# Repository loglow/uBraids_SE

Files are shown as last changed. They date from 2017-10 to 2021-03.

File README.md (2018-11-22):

# µBraids SE (uBraids, microBraids) Eurorack [Rev E]

## 8HP Eurorack module | Voltage-controlled digital oscillator

[µBraids SE](http://ubraids-se.com) is a voltage-controlled digital oscillator/sound source in 8HP with a wide range of creative and useful sound generation algorithms (aka models).

This re-engineered Eurorack module updates and simplifies the classic [Mutable Instruments Braids](https://mutable-instruments.net/modules/braids/) design with a custom brilliant orange LED display module protected by a clear acrylic lens, a low-profile rotary encoder, and an added attenuverter.

Fully compatible with upstream Braids firmware. Includes power cable, mounting hardware, and a one-year warranty. Designed and built with care by [Tall Dog Electronics](http://tall-dog.com) in Western Massachusetts. Licensed [CC BY-SA 4.0](https://creativecommons.org/licenses/by-sa/4.0/) open source hardware.

- **Height:** 3U (128.5 mm)
- **Width:** 8HP (40.3 mm)
- **Depth:** 31 mm (with power)
- **+12V:** 100 mA (average)
- **-12V:** 15 mA (average)

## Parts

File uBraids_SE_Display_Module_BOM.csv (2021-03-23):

Reference | Quantity | Description | Manufacturer | Part Number | Digi-Key P/N
A1 A2 A3 A4 | 4 | DISPLAY 610NM ORN 1DIG 0.4" SMD | Kingbright | ACPSC04-41SEKWA | ACPSC04-41SEKWA-ND
C1 C2 | 2 | CAP CER 0.1UF 50V X7R 0603 | Samsung | CL10B104JB8NNNC | 1276-1033-1-ND
H1 | 1 | CONN HDR 5POS 0.1 STACK T/H GOLD | Samtec | DW-05-15-F-S-200 | DW-05-15-F-S-200-ND
H2 | 1 | CONN HDR 9POS 0.1 STACK T/H GOLD | Samtec | DW-09-15-F-S-200 | N/A
Q1 Q2 Q3 Q4 | 4 | TRANS NPN 40V 0.2A SMD SOT23-3 | Diodes Incorporated | MMBT3904-7-F | MMBT3904-FDICT-ND
R1 R2 R3 R4 | 4 | RES SMD 1K OHM 1% 1/10W 0603 | Panasonic | ERJ-3EKF1001V | P1.00KHCT-ND
R5 R6 R7 R8 R9 R10 R11 R12 R13 R14 R15 R16 R17 R18 | 14 | RES SMD 100 OHM 1% 1/10W 0603 | Panasonic | ERJ-3EKF1000V | P100HCT-ND
U1 U2 | 2 | IC 8BIT SHIFT REGISTER 16-TSSOP | Texas Instruments | SN74HC595PWR | 296-23258-1-ND

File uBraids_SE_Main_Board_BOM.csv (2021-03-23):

Reference | Quantity | Description | Manufacturer | Part Number | Digi-Key P/N
C1 C7 | 2 | CAP CER 18PF 50V NP0 0603 | Samsung | CL10C180FB8NNNC | 1276-2206-1-ND
C2 C3 C4 C5 C6 C10 C11 C15 C17 C18 C21 C23 C26 C28 C29 | 15 | CAP CER 0.1UF 50V X7R 0603 | Samsung | CL10B104JB8NNNC | 1276-1033-1-ND
C8 C9 | 2 | CAP CER 1UF 25V X7R 0603 | Samsung | CL10B105KA8NNNC | 1276-1184-1-ND
C12 C14 | 2 | CAP 22 UF 20% 25 V | Wurth | 865230443003 | 732-8260-1-ND
C13 | 1 | CAP CER 0.47UF 25V X7R 0603 | Samsung | CL10B474KA8NFNC | 1276-2082-1-ND
C16 C19 | 2 | CAP 47 UF 20% 25 V | Wurth | 865230445005 | 732-8262-1-ND
C20 C22 C24 C30 | 4 | CAP CER 1000PF 50V X7R 0603 | Samsung | CL10B102JB8NNNC | 1276-1194-1-ND
C25 C27 | 2 | CAP CER 100PF 50V C0G/NP0 0603 | Samsung | CL10C101FB8NNNC | 1276-2159-1-ND
C31 | 1 | CAP CER 47PF 50V NP0 0603 | Samsung | CL10C470FB8NNNC | 1276-2293-1-ND
C32 | 1 | CAP 10 UF 20% 25 V | Wurth | 865230440002 | 732-8259-1-ND
D1 D2 | 2 | DIODE SCHOTTKY 40V 1A SOD123 | Diodes Incorporated | 1N5819HW-7-F | 1N5819HW-FDICT-ND
H1 | 1 | CONN RCPT 9POS 0.1 GOLD SMD | Samtec | SSM-109-S-SV-BE | SSM-109-S-SV-BE-ND
H2 | 1 | IDC BOX HEADER 0.050 10 POS | CNC Tech | 3220-10-0300-00 | 1175-1629-ND
H4 | 1 | CONN RCPT 5POS 0.1 GOLD SMD | Samtec | SSM-105-S-SV-BE | SSM-105-S-SV-BE-ND
H5 | 1 | CONN HEADER VERT 10POS GOLD | On Shore Technology | 302-S101 | ED1543-ND
J1 J2 J3 J4 J5 J6 | 6 | 3.5MM JACK VERTICAL PCB MOUNT | Wenzhou QingPu | WQP-PJ398SM | N/A
P1 P2 P5 P7 | 4 | POT 9MM LINEAR B10K | Song Huei | R0904N-B10K,L-25KQ/LWS | N/A
P3 P4 P6 | 3 | POT 9MM LINEAR B10K CENTER | Song Huei | R0904N-B10K,L-25KQ/LWS/CC | N/A
Q1 | 1 | TRANS NPN 40V 0.2A SOT23 | ON Semiconductor | MMBT3904LT1G | MMBT3904LT1GOSCT-ND
R1 R5 | 2 | RES SMD 10K OHM 0.1% 1/10W 0603 | Susumu | RG1608P-103-B-T5 | RG16P10.0KBCT-ND
R2 R3 | 2 | RES SMD 100 OHM 1% 1/10W 0603 | Panasonic | ERJ-3EKF1000V | P100HCT-ND
R4 R31 | 2 | RES SMD 1K OHM 0.1% 1/10W 0603 | Susumu | RG1608P-102-B-T5 | RG16P1.0KBCT-ND
R6 R10 R18 R26 R27 R32 | 6 | RES SMD 100K OHM 0.1% 1/10W 0603 | Susumu | RG1608P-104-B-T5 | RG16P100KBCT-ND
R7 | 1 | RES SMD 4.7 OHM 1% 1/2W 0805 | Panasonic | ERJ-6DQF4R7V | P19284CT-ND
R8 | 1 | RES SMD 330 OHM 1% 1/2W 0805 | Panasonic | ERJ-P6WF3300V | P16879CT-ND
R9 | 1 | RES SMD 120K OHM 0.1% 1/10W 0603 | Susumu | RG1608P-124-B-T5 | RG16P120KBCT-ND
R11 R22 R30 | 3 | RES SMD 200K OHM 0.1% 1/10W 0603 | Susumu | RG1608P-204-B-T5 | RG16P200KBCT-ND
R12 R13 R14 R15 R16 R17 R19 R23 R25 R29 R33 | 11 | RES SMD 24.9KOHM 0.1% 1/10W 0603 | Susumu | RG1608P-2492-B-T5 | RG16P24.9KBCT-ND
R20 R28 | 2 | RES SMD 49.9KOHM 0.1% 1/10W 0603 | Susumu | RG1608P-4992-B-T5 | RG16P49.9KBCT-ND
R21 R24 | 2 | RES SMD 39K OHM 0.1% 1/10W 0603 | Susumu | RG1608P-393-B-T5 | RG16P39.0KBCT-ND
S1 | 1 | ENCODER ROTARY | Song Huei | ED1212S-24P-24C-25KC | N/A
U1 | 1 | IC MCU 32BIT 128KB FLASH 48LQFP | STMicroelectronics | STM32F103CBT6 | 497-6288-ND
U2 | 1 | IC DAC 16BIT SNGL W/SPI 8VSSOP | Texas Instruments | DAC8551IADGKT | 296-21222-1-ND
U3 | 1 | IC VREF SHUNT 2.5V SOT23-3 | Texas Instruments | LM4040B25IDBZR | 296-20872-1-ND
U4 | 1 | IC ADC 12BIT 2.7V 4CH SPI14TSSOP | Microchip Technology | MCP3204-CI/ST | MCP3204-CI/ST-ND
U5 | 1 | IC REG LINEAR 3.3V 800MA SOT223 | Texas Instruments | LM1117IMP-3.3/NOPB | LM1117IMP-3.3/NOPBCT-ND
U6 | 1 | IC VREF SHUNT 10V SOT23-3 | Texas Instruments | LM4040B10IDBZR | 296-20869-1-ND
U7 | 1 | IC OPAMP GP 1MHZ RRO 14TSSOP | Microchip Technology | MCP6004T-I/ST | MCP6004T-I/STCT-ND
U8 | 1 | IC OPAMP JFET 3MHZ 14TSSOP | Texas Instruments | TL074CPWR | 296-7198-1-ND
U9 | 1 | IC OPAMP JFET 3MHZ 8TSSOP | Texas Instruments | TL072CPWR | 296-7193-1-ND
X1 | 1 | CRYSTAL 8.0000MHZ 18PF SMD | Abracon | ABM2-8.000MHZ-D4Y-T | 535-10870-1-ND

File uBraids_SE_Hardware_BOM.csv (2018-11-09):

Description | Quantity
Window Lens Insert, Acrylic, 2 mm | 1
Thonkiconn Knurled Nut, Steel, M6 | 6
Threaded Hex Standoff, Brass, M2.5 x 10 mm | 2
Standoff Screw, Button Head, Hex Socket, M2.5 x 6 mm | 2
Standoff Screw, Flat Head, Hex Socket, M2.5 x 6 mm | 2

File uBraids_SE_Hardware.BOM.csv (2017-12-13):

Line | Description | Quantity | Notes
1 | Encoder Spacer, Black PLA, M7 x 2 mm | 1 | 3D printed part
2 | Encoder Shim, Black PLA, 1.2 mm | 1 | 3D printed part
3 | Encoder Washer, Steel, M7 x 0.5 mm | 1 | Included with part S3
4 | Encoder Hex Nut, Steel, M7 | 1 | Included with part S3
5 | Encoder Knob, D-Shaft, Sifam Soft Touch, Black, 10 mm | 1 | https://www.thonk.co.uk/shop/sifam-soft-touch-encoder-knobs/
6 | Thonkiconn Knurled Nut, Steel, M6 | 6 | https://www.thonk.co.uk/shop/3-5mm-jacks/
7 | Threaded Hex Standoff, Brass, M2.5 x 10 mm | 2 | https://www.ebay.com/itm/141137666898
8 | Standoff Screw, Button Head, Hex Socket, Black, M2.5 x 6 mm | 4 | https://www.ebay.com/itm/162503642542

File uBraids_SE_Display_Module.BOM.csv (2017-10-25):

Line | Reference | Quantity | Description | Package | Manufacturer | Part Number | Digi-Key P/N
1 | A1,A2,A3,A4 | 4 | DISPLAY 610NM ORN 1DIG 0.4" SMD | N/A | Kingbright | ACPSC04-41SEKWA | ACPSC04-41SEKWA-ND
2 | C1,C2 | 2 | CAP CER 0.1UF 50V X7R 0603 | 0603 | Samsung | CL10B104JB8NNNC | 1276-1033-1-ND
3 | H1 | 1 | .025" BOARD SPACERS | N/A | Samtec | DW-05-07-T-S-200 | DW-05-07-T-S-200-ND
4 | H2 | 1 | .025" BOARD SPACERS | N/A | Samtec | DW-09-07-T-S-200 | DW-09-07-T-S-200-ND
5 | Q1,Q2,Q3,Q4 | 4 | TRANS NPN 40V 0.2A SC70-3 | SOT-323 | Diodes Incorporated | MMST3904-7-F | MMST3904-FDICT-ND
6 | R1,R2,R3,R4 | 4 | RES SMD 1K OHM 1% 1/10W 0603 | 0603 | Panasonic | ERJ-3EKF1001V | P1.00KHCT-ND
7 | R5,R6,R7,R8,R9,R10,R11,R12,R13,R14,R15,R16,R17,R18 | 14 | RES SMD 100 OHM 1% 1/10W 0603 | 0603 | Panasonic | ERJ-3EKF1000V | P100HCT-ND
8 | U1,U2 | 2 | IC 8BIT SHIFT REGISTER 16-TSSOP | TSSOP-16 | Texas Instruments | SN74HC595PWR | 296-23258-1-ND

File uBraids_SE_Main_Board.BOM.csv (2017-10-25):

Line | Reference | Quantity | Description | Package | Manufacturer | Part Number | Digi-Key P/N
1 | A1 | 1 | 4X14-SEGMENT 10MM DISPLAY | N/A | N/A | N/A | N/A
2 | C1,C6 | 2 | CAP CER 18PF 50V NP0 0603 | 0603 | Samsung | CL10C180FB8NNNC | 1276-2206-1-ND
3 | C2,C3,C4,C5,C8,C10,C14,C16,C17,C20,C22,C25,C26,C28 | 14 | CAP CER 0.1UF 50V X7R 0603 | 0603 | Samsung | CL10B104JB8NNNC | 1276-1033-1-ND
4 | C7,C9 | 2 | CAP CER 1UF 25V X7R 0603 | 0603 | Samsung | CL10B105KA8NNNC | 1276-1184-1-ND
5 | C11 | 1 | CAP CER 0.47UF 25V X7R 0603 | 0603 | Samsung | CL10B474KA8NFNC | 1276-2082-1-ND
6 | C12,C13 | 2 | CAP 22 UF 20% 25 V | N/A | Wurth Electronics | 865230443003 | 732-8260-1-ND
7 | C15,C18 | 2 | CAP 47 UF 20% 25 V | N/A | Wurth Electronics | 865230445005 | 732-8262-1-ND
8 | C19,C21,C23,C29 | 4 | CAP CER 1000PF 50V X7R 0603 | 0603 | Samsung | CL10B102JB8NNNC | 1276-1194-1-ND
9 | C24,C27 | 2 | CAP CER 100PF 50V C0G/NP0 0603 | 0603 | Samsung | CL10C101FB8NNNC | 1276-2159-1-ND
10 | C30 | 1 | CAP CER 47PF 50V NP0 0603 | 0603 | Samsung | CL10C470FB8NNNC | 1276-2293-1-ND
11 | C31 | 1 | CAP 10 UF 20% 25 V | N/A | Wurth Electronics | 865230440002 | 732-8259-1-ND
12 | D1,D2 | 2 | DIODE SCHOTTKY 40V 1A SOD123 | SOD-123 | Diodes Incorporated | 1N5819HW-7-F | 1N5819HW-FDICT-ND
13 | H1 | 1 | IDC BOX HEADER 0.050 10 POS | N/A | CNC Tech | 3220-10-0300-00 | 1175-1629-ND
14 | H2 | 1 | CONN HEADER XH TOP 6POS 2.5MM | N/A | JST | B6B-XH-A(LF)(SN) | 455-2271-ND
15 | H3 | 1 | CONN HEADER VERT 10POS GOLD | N/A | On Shore Technology | 302-S101 | ED1543-ND
16 | J1,J2,J3,J4,J5,J6 | 6 | THONKICONN 3.5MM JACK | N/A | Thonk | PJ301M-12 | N/A
17 | P1,P2,P3,P4,P5,P6 | 6 | B10K LINEAR 9MM POT | N/A | Thonk | R0904N-B10K,L-25KQ | N/A
18 | Q1 | 1 | TRANS NPN 40V 0.2A SOT23 | SOT-23 | ON Semiconductor | MMBT3904LT1G | MMBT3904LT1GOSCT-ND
19 | R1,R2,R5 | 3 | RES SMD 10K OHM 1% 1/10W 0603 | 0603 | Panasonic | ERJ-3EKF1002V | P10.0KHCT-ND
20 | R3,R30 | 2 | RES SMD 1K OHM 1% 1/10W 0603 | 0603 | Panasonic | ERJ-3EKF1001V | P1.00KHCT-ND
21 | R4 | 1 | RES SMD 4.7 OHM 1% 1/2W 0805 | 0805 | Panasonic | ERJ-6DQF4R7V | P19284CT-ND
22 | R6,R8,R17,R25,R26,R31 | 6 | RES SMD 100K OHM 1% 1/10W 0603 | 0603 | Panasonic | ERJ-3EKF1003V | P100KHCT-ND
23 | R7 | 1 | RES SMD 330 OHM 1% 1/2W 0805 | 0805 | Panasonic | ERJ-P6WF3300V | P16879CT-ND
24 | R9,R22,R29 | 3 | RES SMD 200K OHM 1% 1/10W 0603 | 0603 | Panasonic | ERJ-3EKF2003V | P200KHCT-ND
25 | R10,R12,R13,R14,R15,R16,R18,R21,R23,R28,R32 | 11 | RES SMD 24.9K OHM 1% 1/10W 0603 | 0603 | Panasonic | ERJ-3EKF2492V | P24.9KHCT-ND
26 | R11 | 1 | RES SMD 120K OHM 1% 1/10W 0603 | 0603 | Panasonic | ERJ-3EKF1203V | P120KHCT-ND
27 | R19,R27 | 2 | RES SMD 49.9K OHM 1% 1/10W 0603 | 0603 | Panasonic | ERJ-3EKF4992V | P49.9KHCT-ND
28 | R20,R24 | 2 | RES SMD 39K OHM 1% 1/10W 0603 | 0603 | Panasonic | ERJ-3EKF3902V | P39.0KHCT-ND
29 | S1,S2 | 2 | SWITCH TACTILE SPST-NO 0.02A 15V | N/A | Panasonic | EVQ-Q2K01W | P12941SCT-ND
30 | S3 | 1 | ENCODER ROTARY | N/A | Bourns | PEC11R-4220F-S0024 | PEC11R-4220F-S0024-ND
31 | U1 | 1 | IC MCU 32BIT 128KB FLASH 48LQFP | LQFP-48 | STMicroelectronics | STM32F103CBT6 | 497-6288-ND
32 | U2 | 1 | IC DAC 16BIT SNGL W/SPI 8VSSOP | VSSOP-8 | Texas Instruments | DAC8551IADGKT | 296-21222-1-ND
33 | U3 | 1 | IC VREF SHUNT 2.5V SOT23-3 | SOT-23 | Texas Instruments | LM4040B25IDBZR | 296-20872-1-ND
34 | U4 | 1 | IC ADC 12BIT 2.7V 4CH SPI14TSSOP | TSSOP-14 | Microchip Technology | MCP3204-CI/ST | MCP3204-CI/ST-ND
35 | U5 | 1 | IC REG LDO 3.3V 0.8A 8WSON | WSON-8 | Texas Instruments | LM1117LD-3.3/NOPB | LM1117LD-3.3/NOPBCT-ND
36 | U6 | 1 | IC VREF SHUNT 10V SOT23-3 | SOT-23 | Texas Instruments | LM4040B10IDBZR | 296-20869-1-ND
37 | U7 | 1 | IC OPAMP GP 1MHZ RRO 14TSSOP | TSSOP-14 | Microchip Technology | MCP6004T-I/ST | MCP6004T-I/STCT-ND
38 | U8 | 1 | IC OPAMP JFET 3MHZ 14TSSOP | TSSOP-14 | Texas Instruments | TL074CPWR | 296-7198-1-ND
39 | U9 | 1 | IC OPAMP JFET 3MHZ 8TSSOP | TSSOP-8 | Texas Instruments | TL072CPWR | 296-7193-1-ND
40 | X1 | 1 | CRYSTAL 8.0000MHZ 18PF SMD | N/A | Abracon | ABM2-8.000MHZ-D4Y-T | 535-10870-1-ND

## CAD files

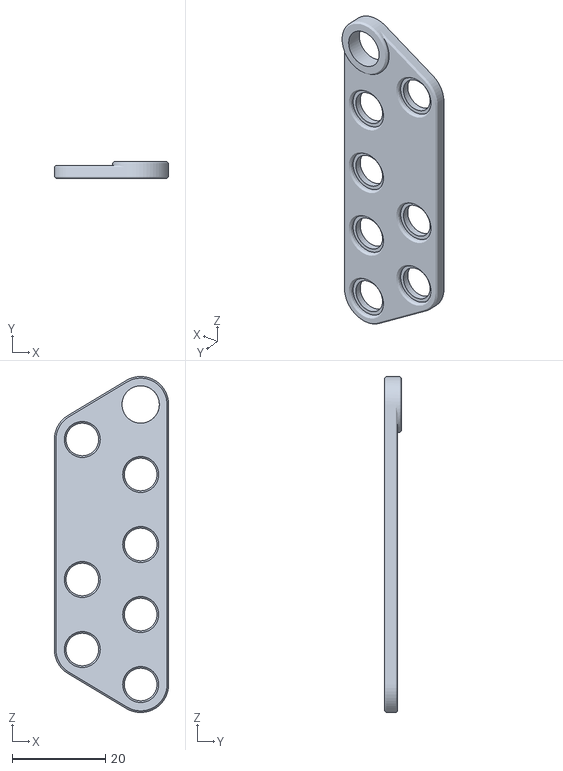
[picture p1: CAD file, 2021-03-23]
uBraids_SE_Assembly_Spacer.stl
24.5 x 3.60 x 72.0

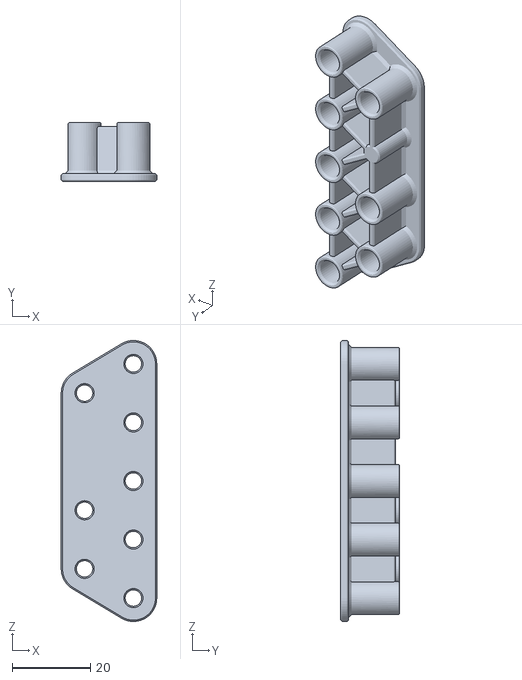
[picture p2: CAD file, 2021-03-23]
uBraids_SE_Assembly_Cap.stl
24.5 x 15.0 x 72.0

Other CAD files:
uBraids_SE_Model.skp

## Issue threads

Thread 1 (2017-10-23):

top and bottom rail clearance is way too small

av500, 2017-10-23:
Eurorack has about 9mm top and bottom clearance, leaving ~110mm for the PCB. you have only 6.5mm on the top and ~7mm on the bottom which makes the module not fit with most Eurorack rails.

loglow, 2017-10-23:
Hi av500, thanks for submitting the feedback.

We're aware of this, and in fact, I've already done a bunch of work to correct it. We tested the module with a number of different rails, but clearly not enough! Further research showed us that while some rails do have > 115 mm clearance, there are also many with 111-112 mm clearance.

The main board has already been shaved down from 115 mm to 110.5 mm and re-centered relative to the front panel. I'll be updating the repo here with the new files very shortly. I may still try to eliminate another 0.5 mm just for good measure.

Thanks again,
Dan

loglow, 2017-10-23:
Updated revised files to address the rail clearance issue.

loglow, 2017-10-24:
Updated again with a 110 mm version.

Closed 2017-10-23.

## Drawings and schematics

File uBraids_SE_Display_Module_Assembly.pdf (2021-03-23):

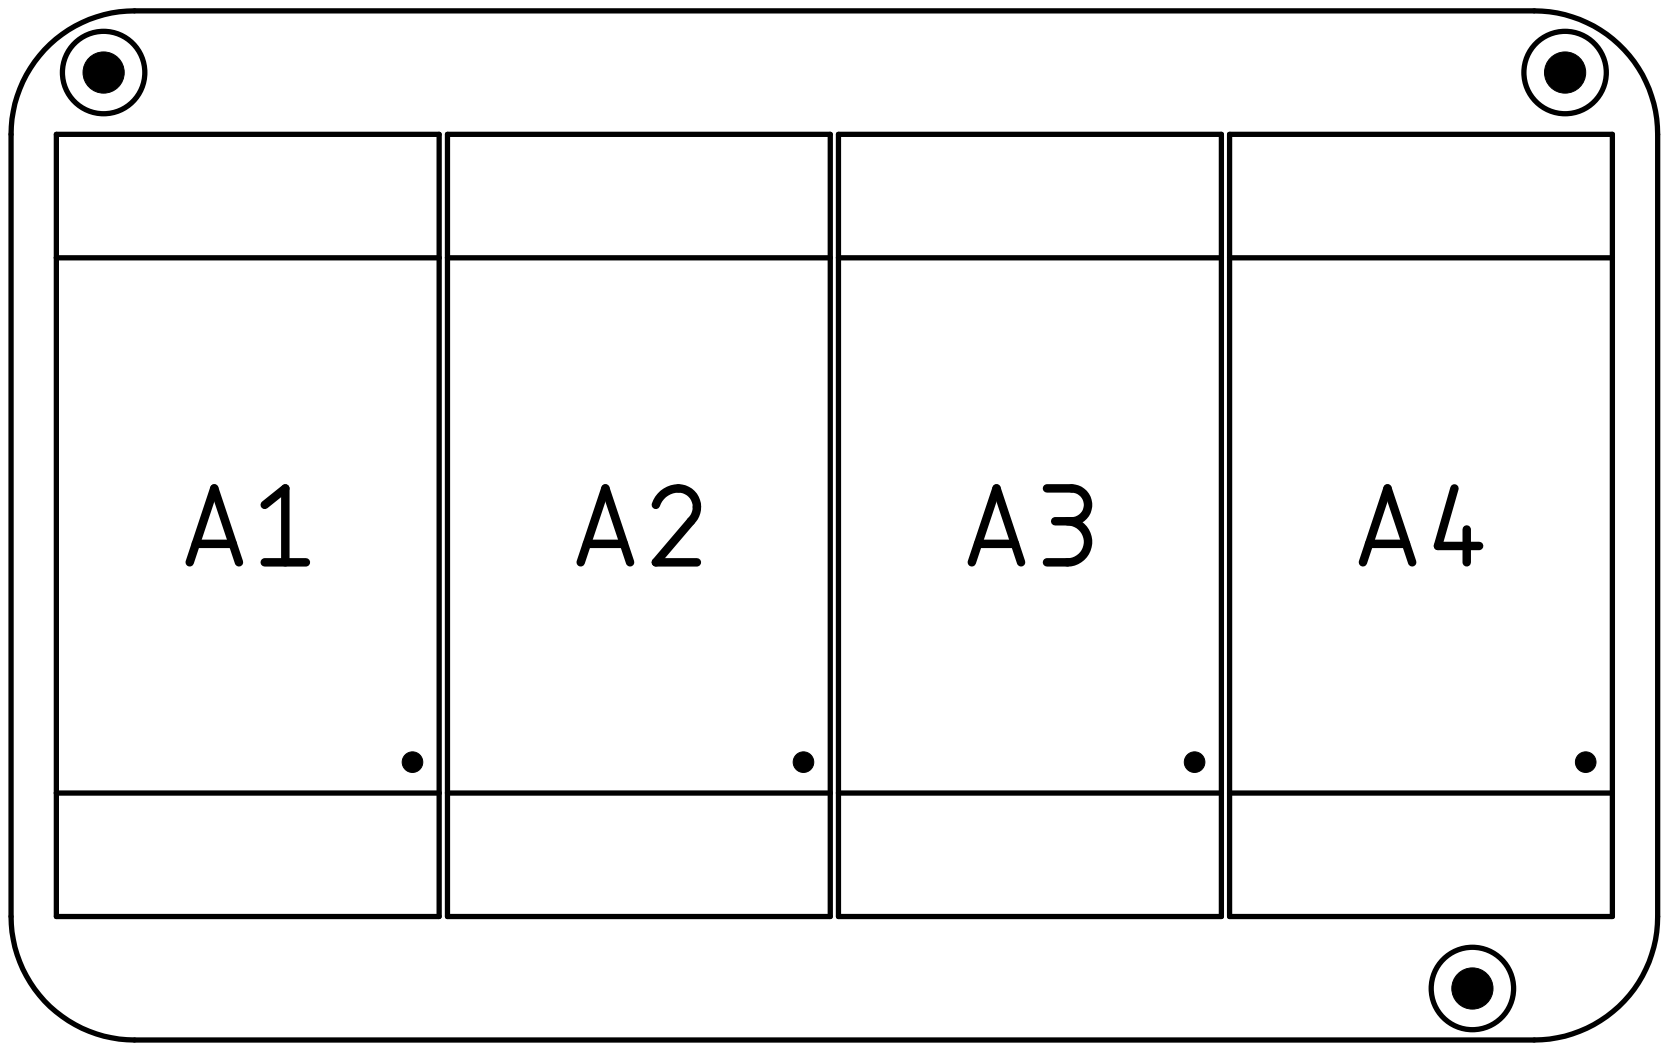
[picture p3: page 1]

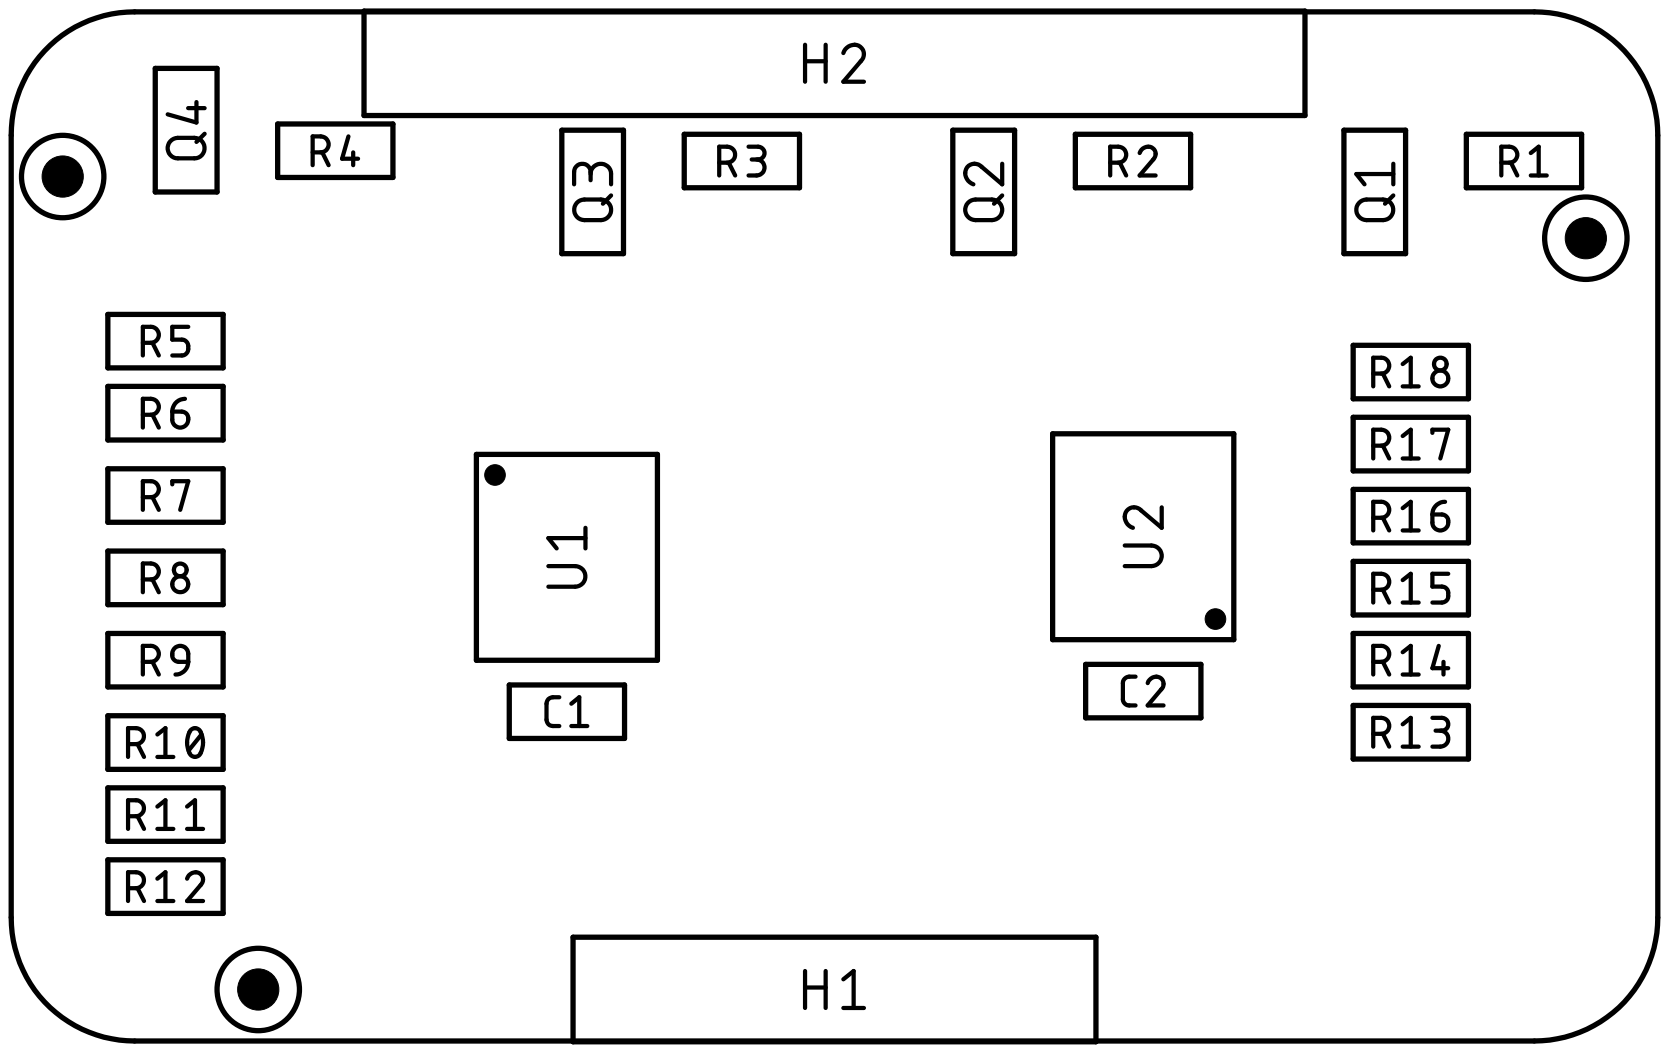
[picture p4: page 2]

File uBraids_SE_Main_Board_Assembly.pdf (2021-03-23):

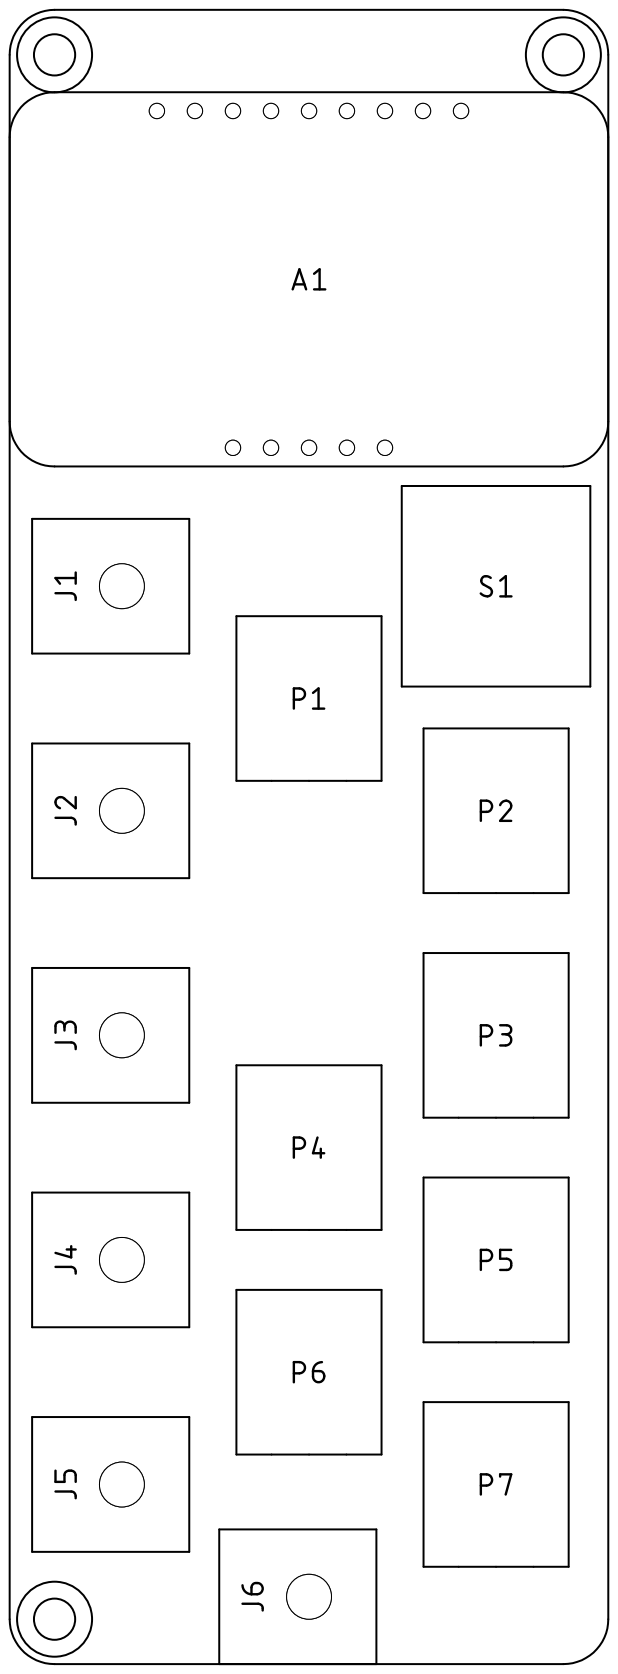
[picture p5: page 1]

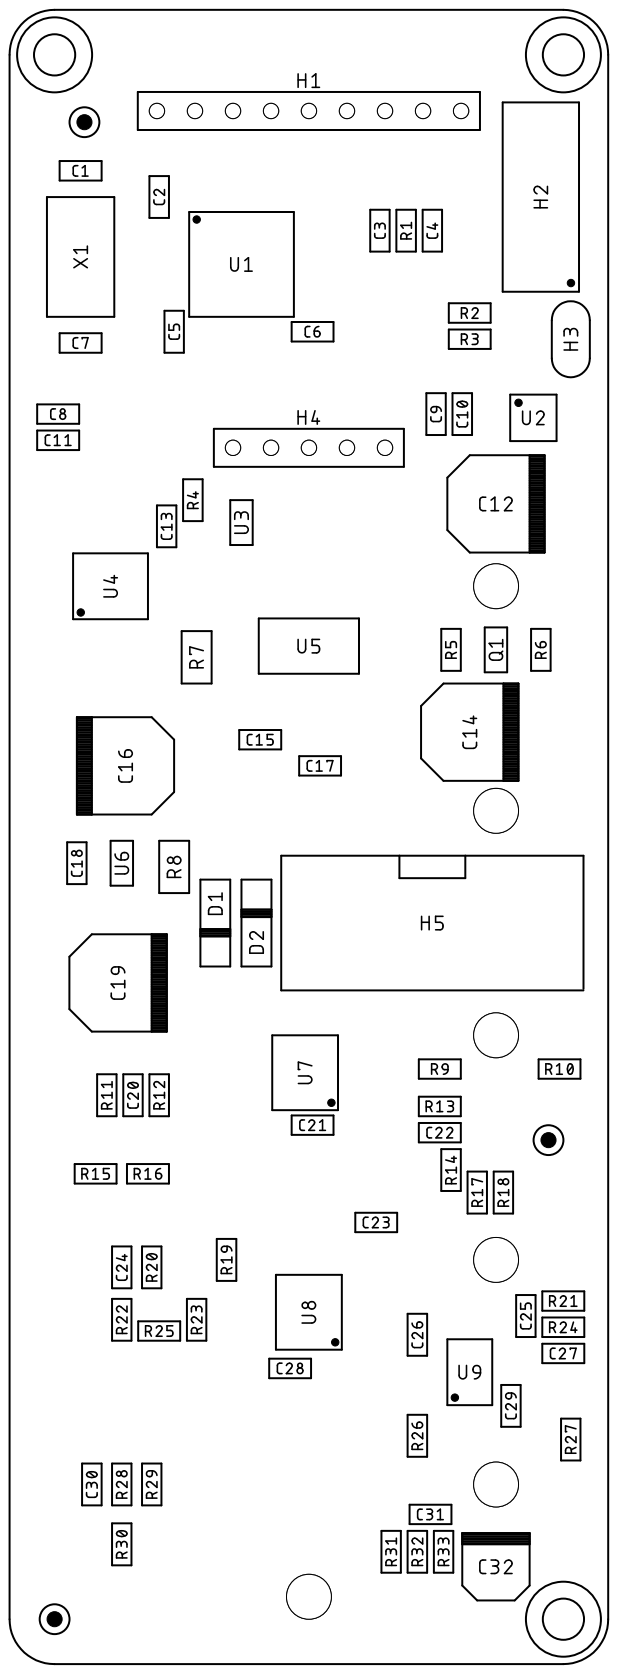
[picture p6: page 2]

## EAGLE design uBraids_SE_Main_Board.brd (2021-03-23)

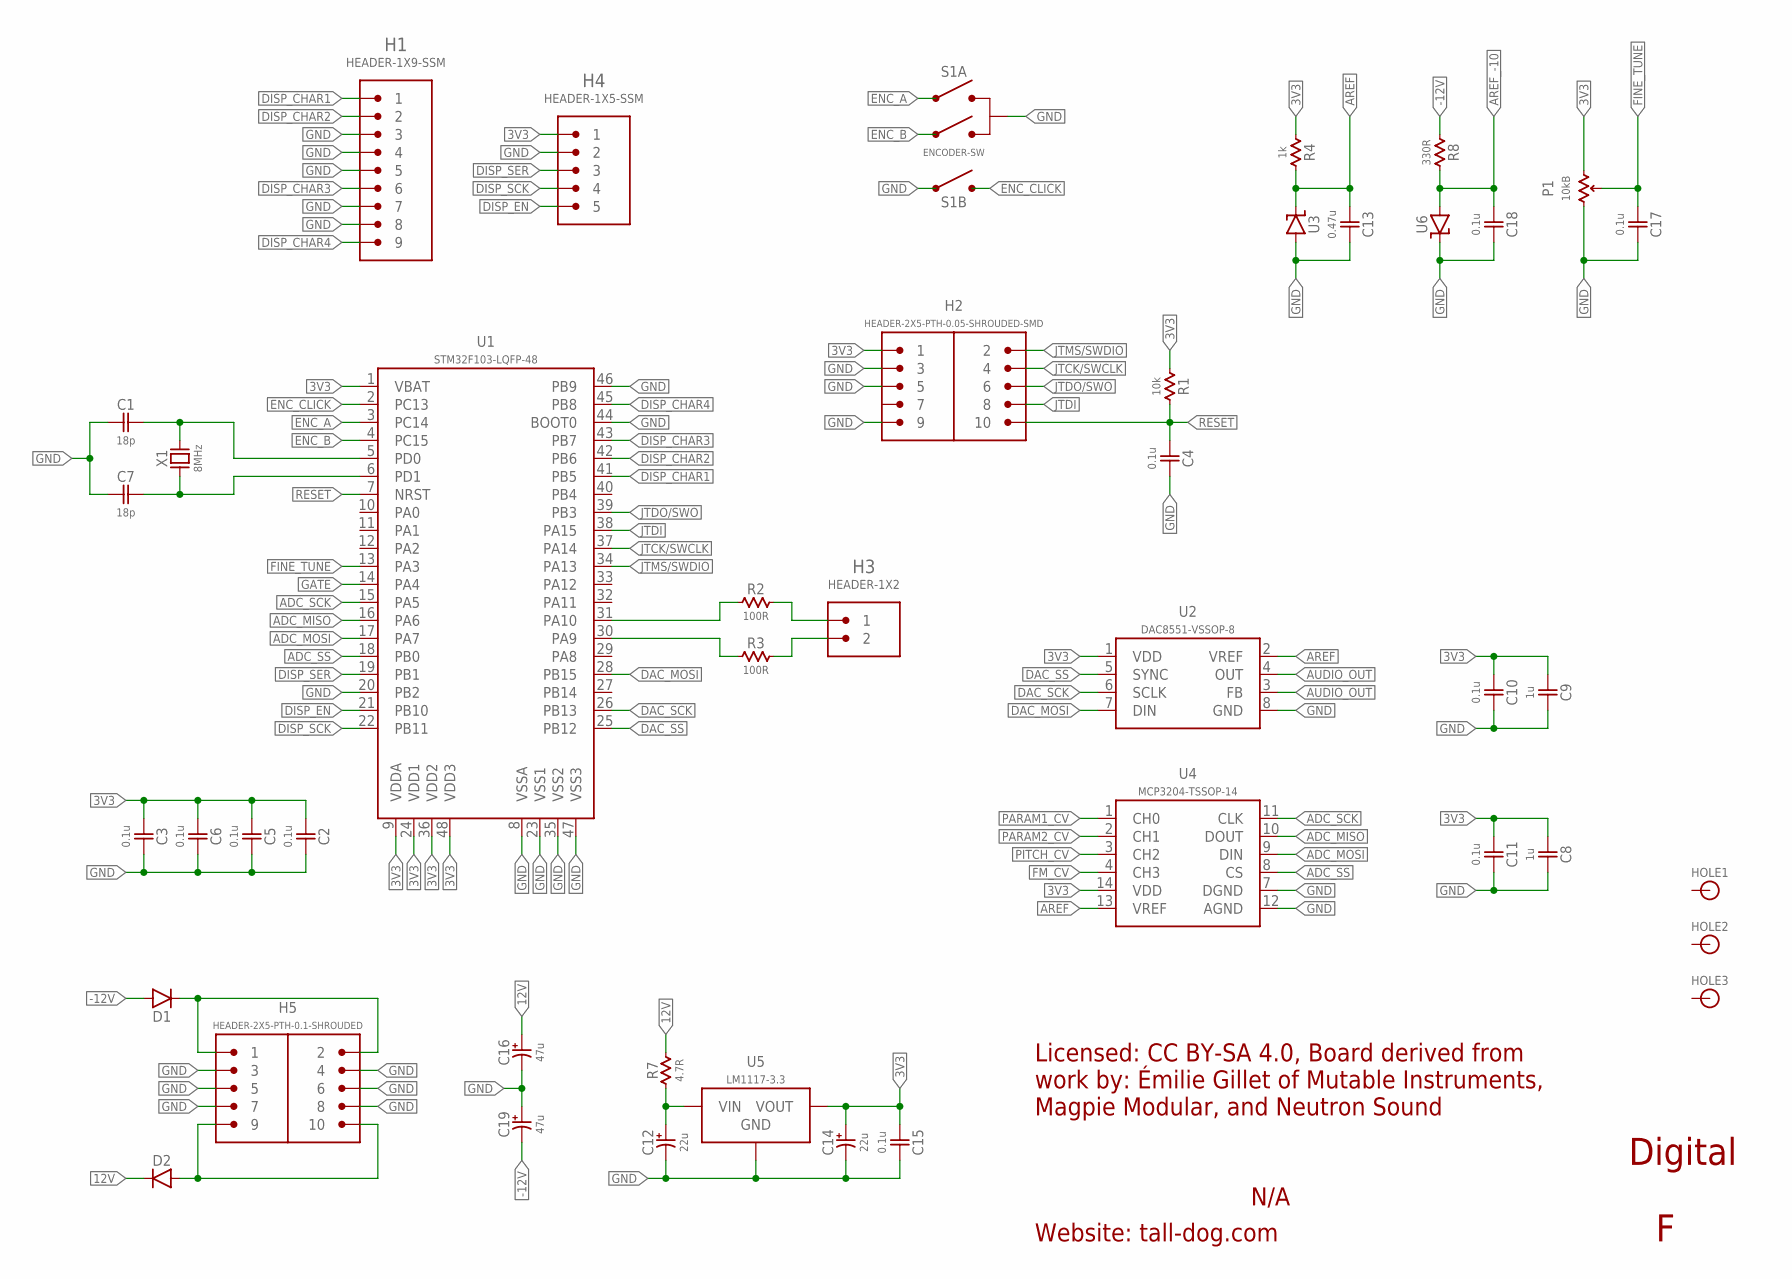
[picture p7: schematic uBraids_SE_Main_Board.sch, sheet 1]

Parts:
C1, C7: 18p; 0603-NP
C2, C3, C4, C5, C6, C10, C11, C15, C17, C18: 0.1u; 0603-NP
C8, C9: 1u; 0603-NP
C12, C14: 22u; ELECTRO-SMD-6.6MM
C13: 0.47u; 0603-NP
C16, C19: 47u; ELECTRO-SMD-6.6MM
D1, D2: 1N5819HW; SOD-123
H1: HEADER-1X9-SSM; SSM-109-S-SV-BE
H2: HEADER-2X5-PTH-0.05-SHROUDED-SMD; PTH-0.05-2X5-SHROUDED-SMD
H3: HEADER-1X2; PTH-0.1-1X2
H4: HEADER-1X5-SSM; SSM-105-S-SV-BE
H5: HEADER-2X5-PTH-0.1-SHROUDED; PTH-0.1-2X5-SHROUDED
HOLE1, HOLE2, HOLE3: HOLE; M2.5-HOLE
P1: 10kB; POT
R1: 10k; 0603-NP
R2, R3: 100R; 0603-NP
R4: 1k; 0603-NP
R7: 4.7R; 0805-NP
R8: 330R; 0805-NP
S1: ENCODER-SW; ENCODER-EC12E
U1: STM32F103-LQFP-48; LQFP-48
U2: DAC8551-VSSOP-8; VSSOP-8
U3: LM4040B25; SOT-23
U4: MCP3204-TSSOP-14; TSSOP-14
U5: LM1117-3.3; SOT-223
U6: LM4040B10; SOT-23
X1: 8MHz; CRYSTAL-ABM2

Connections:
3V3: C2.1, C3.1, C5.1, C6.1, C8.1, C9.1, C10.1, C11.1, C14.A (POS), C15.1, H2.1, H4.1, P1.P$1 (E), R1.1, R4.1, U1.1 (VBAT), U1.9 (VDDA), U1.24 (VDD1), U1.36 (VDD2), U1.48 (VDD3), U2.1 (VDD), U4.14 (VDD), U5.2 (VOUT), U5.4 (VOUT); also elsewhere on the board
12V: C16.A (POS), D2.C, R7.2; also elsewhere on the board
12V_BUS: D2.A, H5.9, H5.10
12V_U5: C12.A (POS), R7.1, U5.3 (VIN)
-12V: C19.C (NEG), D1.A, R8.1; also elsewhere on the board
-12V_BUS: D1.C, H5.1, H5.2
ADC_MISO: U1.16 (PA6), U4.10 (DOUT)
ADC_MOSI: U1.17 (PA7), U4.9 (DIN)
ADC_SCK: U1.15 (PA5), U4.11 (CLK)
ADC_SS: U1.18 (PB0), U4.8 (CS)
AREF: C13.1, R4.2, U2.2 (VREF), U3.1 (C), U4.13 (VREF)
AREF_-10: C18.1, R8.2, U6.2 (A); also elsewhere on the board
AUDIO_OUT: U2.3 (FB), U2.4 (OUT); also elsewhere on the board
DAC_MOSI: U1.28 (PB15), U2.7 (DIN)
DAC_SCK: U1.26 (PB13), U2.6 (SCLK)
DAC_SS: U1.25 (PB12), U2.5 (SYNC)
DISP_CHAR1: H1.1, U1.41 (PB5)
DISP_CHAR2: H1.2, U1.42 (PB6)
DISP_CHAR3: H1.6, U1.43 (PB7)
DISP_CHAR4: H1.9, U1.45 (PB8)
DISP_EN: H4.5, U1.21 (PB10)
DISP_SCK: H4.4, U1.22 (PB11)
DISP_SER: H4.3, U1.19 (PB1)
ENC_A: S1.B, U1.3 (PC14)
ENC_B: S1.A, U1.4 (PC15)
ENC_CLICK: S1.E (2), U1.2 (PC13)
FINE_TUNE: C17.1, P1.P$2 (S), U1.13 (PA3)
FM_CV: U4.4 (CH3); also elsewhere on the board
GATE: U1.14 (PA4); also elsewhere on the board
GND: C1.1, C2.2, C3.2, C4.2, C5.2, C6.2, C7.1, C8.2, C9.2, C10.2, C11.2, C12.C (NEG), C13.2, C14.C (NEG), C15.2, C16.C (NEG), C17.2, C18.2, C19.A (POS), H1.3, H1.4, H1.5, H1.7, H1.8, H2.3, H2.5, H2.9, H4.2, H5.3, H5.4, H5.5, H5.6, H5.7, H5.8, P1.P$3 (A), S1.C, S1.D (1), U1.8 (VSSA), U1.20 (PB2), U1.23 (VSS1), U1.35 (VSS2), U1.44 (BOOT0), U1.46 (PB9), U1.47 (VSS3), U2.8 (GND), U3.2 (A), U4.7 (DGND), U4.12 (AGND), U5.1 (GND), U6.1 (C); also elsewhere on the board
JTCK/SWCLK: H2.4, U1.37 (PA14)
JTDI: H2.8, U1.38 (PA15)
JTDO/SWO: H2.6, U1.39 (PB3)
JTMS/SWDIO: H2.2, U1.34 (PA13)
PARAM1_CV: U4.1 (CH0); also elsewhere on the board
PARAM2_CV: U4.2 (CH1); also elsewhere on the board
PD0-XTAL: C1.2, U1.5 (PD0), X1.2
PD1-XTAL: C7.2, U1.6 (PD1), X1.1
PITCH_CV: U4.3 (CH2); also elsewhere on the board
RESET: C4.1, H2.10, R1.2, U1.7 (NRST)
RX: H3.1, R2.2
RX_R: R2.1, U1.31 (PA10)
TX: H3.2, R3.2
TX_R: R3.1, U1.30 (PA9)

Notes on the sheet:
Licensed: CC BY-SA 4.0, Board derived from work by: Émilie Gillet of Mutable Instruments, Magpie Modular, and Neutron Sound
Website: tall-dog.com
N/A
Digital

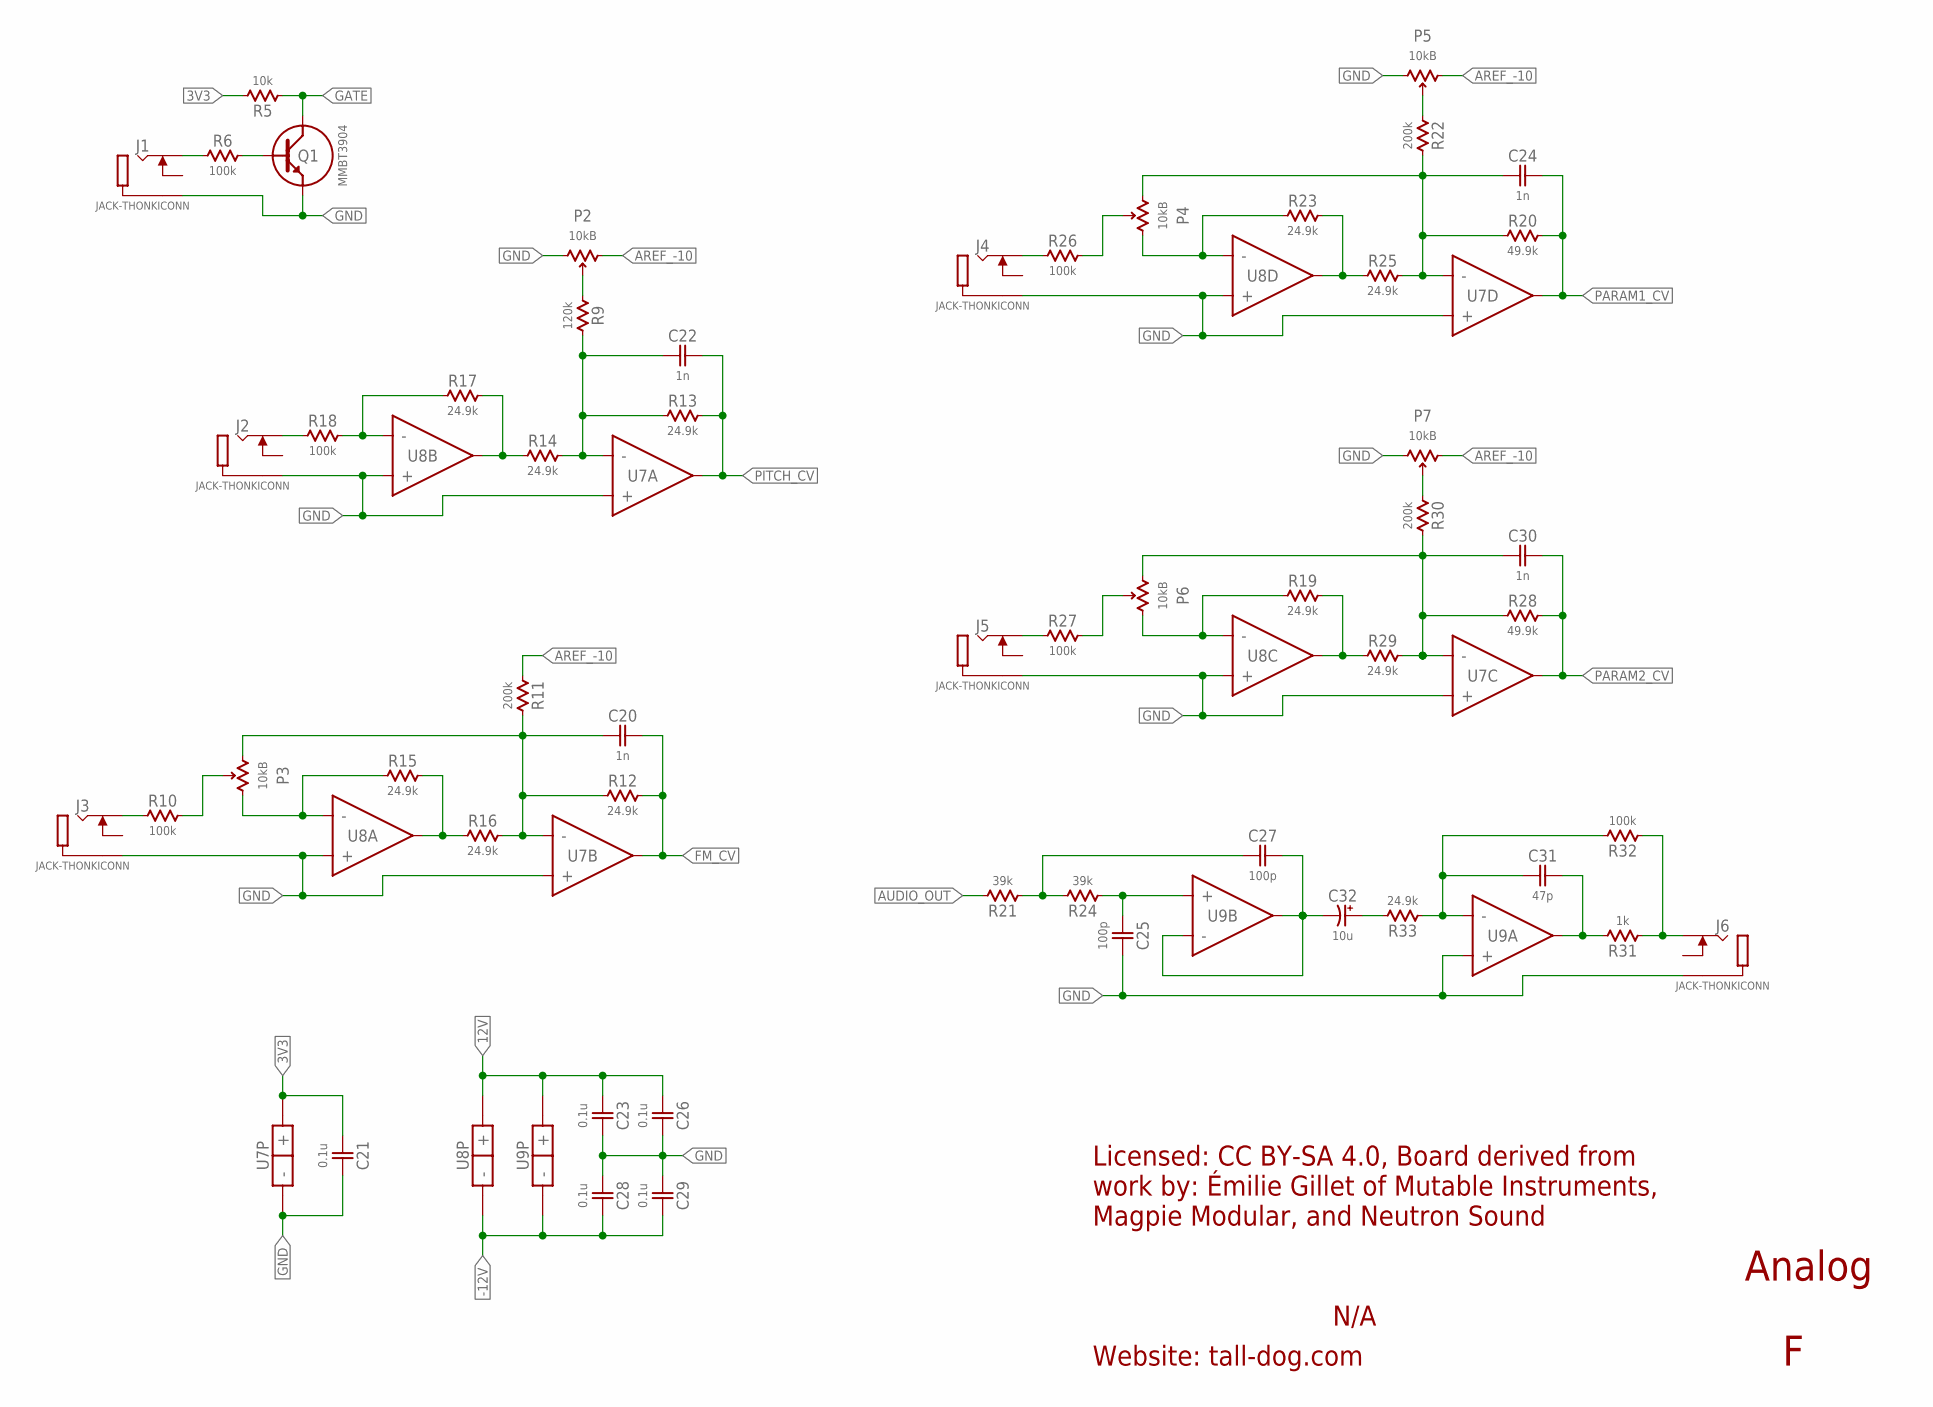
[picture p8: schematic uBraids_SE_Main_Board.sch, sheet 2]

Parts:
C20, C22, C24, C30: 1n; 0603-NP
C21, C23, C26, C28, C29: 0.1u; 0603-NP
C25, C27: 100p; 0603-NP
C31: 47p; 0603-NP
C32: 10u; ELECTRO-SMD-4.3MM
J1, J2, J3, J4, J5, J6: JACK-THONKICONN; THONKICONN
P2, P3, P4, P5, P6, P7: 10kB; POT
Q1: MMBT3904; SOT-23
R5: 10k; 0603-NP
R6, R10, R18, R26, R27, R32: 100k; 0603-NP
R9: 120k; 0603-NP
R11, R22, R30: 200k; 0603-NP
R12, R13, R14, R15, R16, R17, R19, R23, R25, R29, R33: 24.9k; 0603-NP
R20, R28: 49.9k; 0603-NP
R21, R24: 39k; 0603-NP
R31: 1k; 0603-NP
U7: MCP6004; TSSOP-14
U8: TL074-TSSOP-14; TSSOP-14
U9: TL072; TSSOP-8

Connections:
3V3: C21.1, R5.2, U7.4 (+); also elsewhere on the board
12V: C23.1, C26.1, U8.4 (+), U9.8 (+); also elsewhere on the board
-12V: C28.2, C29.2, U8.11 (-), U9.4 (-); also elsewhere on the board
AREF_-10: P2.P$1 (E), P5.P$1 (E), P7.P$1 (E), R11.1; also elsewhere on the board
AUDIO_OUT: R21.2; also elsewhere on the board
FM_CV: C20.2, R12.2, U7.7 (OUT); also elsewhere on the board
GATE: Q1.3 (C), R5.1; also elsewhere on the board
GND: C21.2, C23.2, C25.2, C26.2, C28.1, C29.1, J1.P1 (1), J2.P1 (1), J3.P1 (1), J4.P1 (1), J5.P1 (1), J6.P1 (1), P2.P$3 (A), P5.P$3 (A), P7.P$3 (A), Q1.2 (E), U7.3 (+), U7.5 (+), U7.10 (+), U7.11 (-), U7.12 (+), U8.3 (+), U8.5 (+), U8.10 (+), U8.12 (+), U9.3 (+); also elsewhere on the board
unnamed: P6.P$2 (S), R27.2
unnamed: C24.1, P4.P$3 (A), R20.1, R22.2, R25.2, U7.13 (-)
unnamed: R14.1, R17.2, U8.7 (OUT)
unnamed: P2.P$2 (S), R9.1
unnamed: J2.P3 (3), R18.1
unnamed: C22.1, R9.2, R13.1, R14.2, U7.2 (-)
unnamed: R17.1, R18.2, U8.6 (-)
unnamed: J3.P3 (3), R10.1
unnamed: J4.P3 (3), R26.1
unnamed: P3.P$2 (S), R10.2
unnamed: P4.P$1 (E), R23.1, U8.13 (-)
unnamed: R23.2, R25.1, U8.14 (OUT)
unnamed: P3.P$1 (E), R15.1, U8.2 (-)
unnamed: R15.2, R16.1, U8.1 (OUT)
unnamed: C20.1, P3.P$3 (A), R11.2, R12.1, R16.2, U7.6 (-)
unnamed: J1.P3 (3), R6.1
unnamed: R19.2, R29.1, U8.8 (OUT)
unnamed: J5.P3 (3), R27.1
unnamed: P5.P$2 (S), R22.1
unnamed: P4.P$2 (S), R26.2
unnamed: P6.P$1 (E), R19.1, U8.9 (-)
unnamed: P7.P$2 (S), R30.1
unnamed: Q1.1 (B), R6.2
unnamed: C27.2, C32.C (NEG), U9.6 (-), U9.7 (OUT)
unnamed: C32.A (POS), R33.2
unnamed: C25.1, R24.1, U9.5 (+)
unnamed: C30.1, P6.P$3 (A), R28.1, R29.2, R30.2, U7.9 (-)
unnamed: C27.1, R21.1, R24.2
unnamed: J6.P3 (3), R31.1, R32.1
unnamed: C31.2, R31.2, U9.1 (OUT)
unnamed: C31.1, R32.2, R33.1, U9.2 (-)
PARAM1_CV: C24.2, R20.2, U7.14 (OUT); also elsewhere on the board
PARAM2_CV: C30.2, R28.2, U7.8 (OUT); also elsewhere on the board
PITCH_CV: C22.2, R13.2, U7.1 (OUT); also elsewhere on the board

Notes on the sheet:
Licensed: CC BY-SA 4.0, Board derived from work by: Émilie Gillet of Mutable Instruments, Magpie Modular, and Neutron Sound
Website: tall-dog.com
Analog
N/A

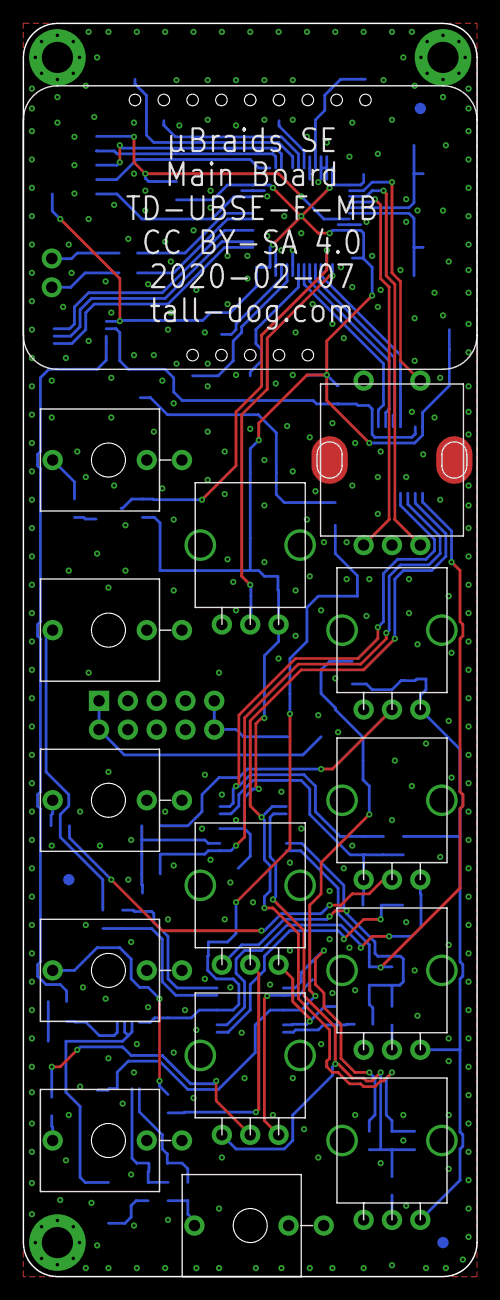
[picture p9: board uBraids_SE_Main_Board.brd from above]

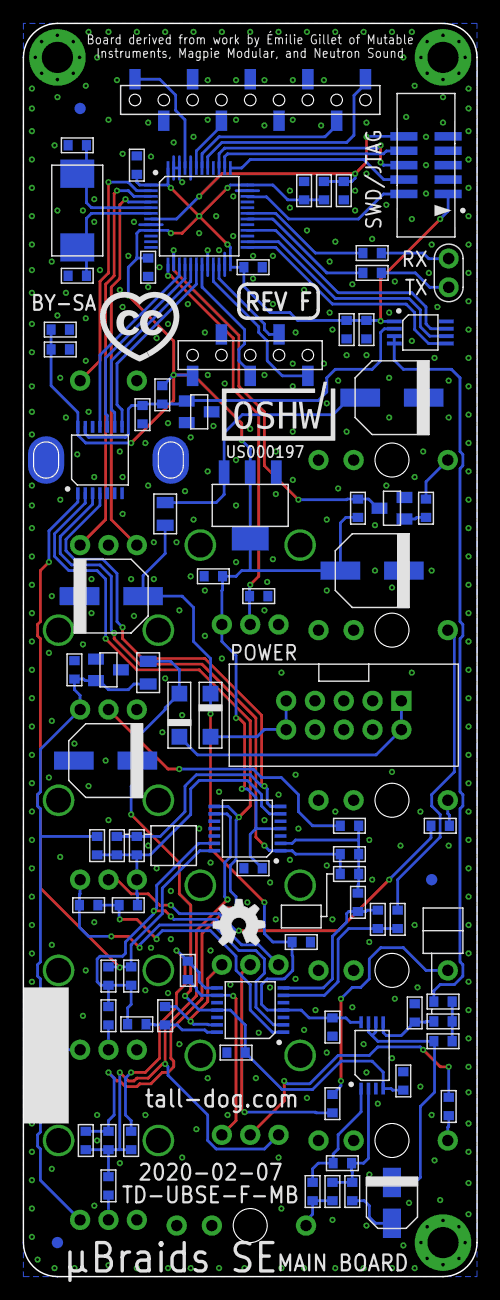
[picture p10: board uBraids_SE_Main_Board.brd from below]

Board: 2 copper layers, 40.0 x 110.5 mm, 108 parts (90 on the bottom side), 75 nets.

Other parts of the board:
A1: DISPLAY-MODULE-OUTLINE
U$1, U$6, U$7: FIDUCIAL
U$2: LOGO-REV
U$3: LOGO-OSH
U$4: LOGO-CC
U$8: LOGO-OSHW

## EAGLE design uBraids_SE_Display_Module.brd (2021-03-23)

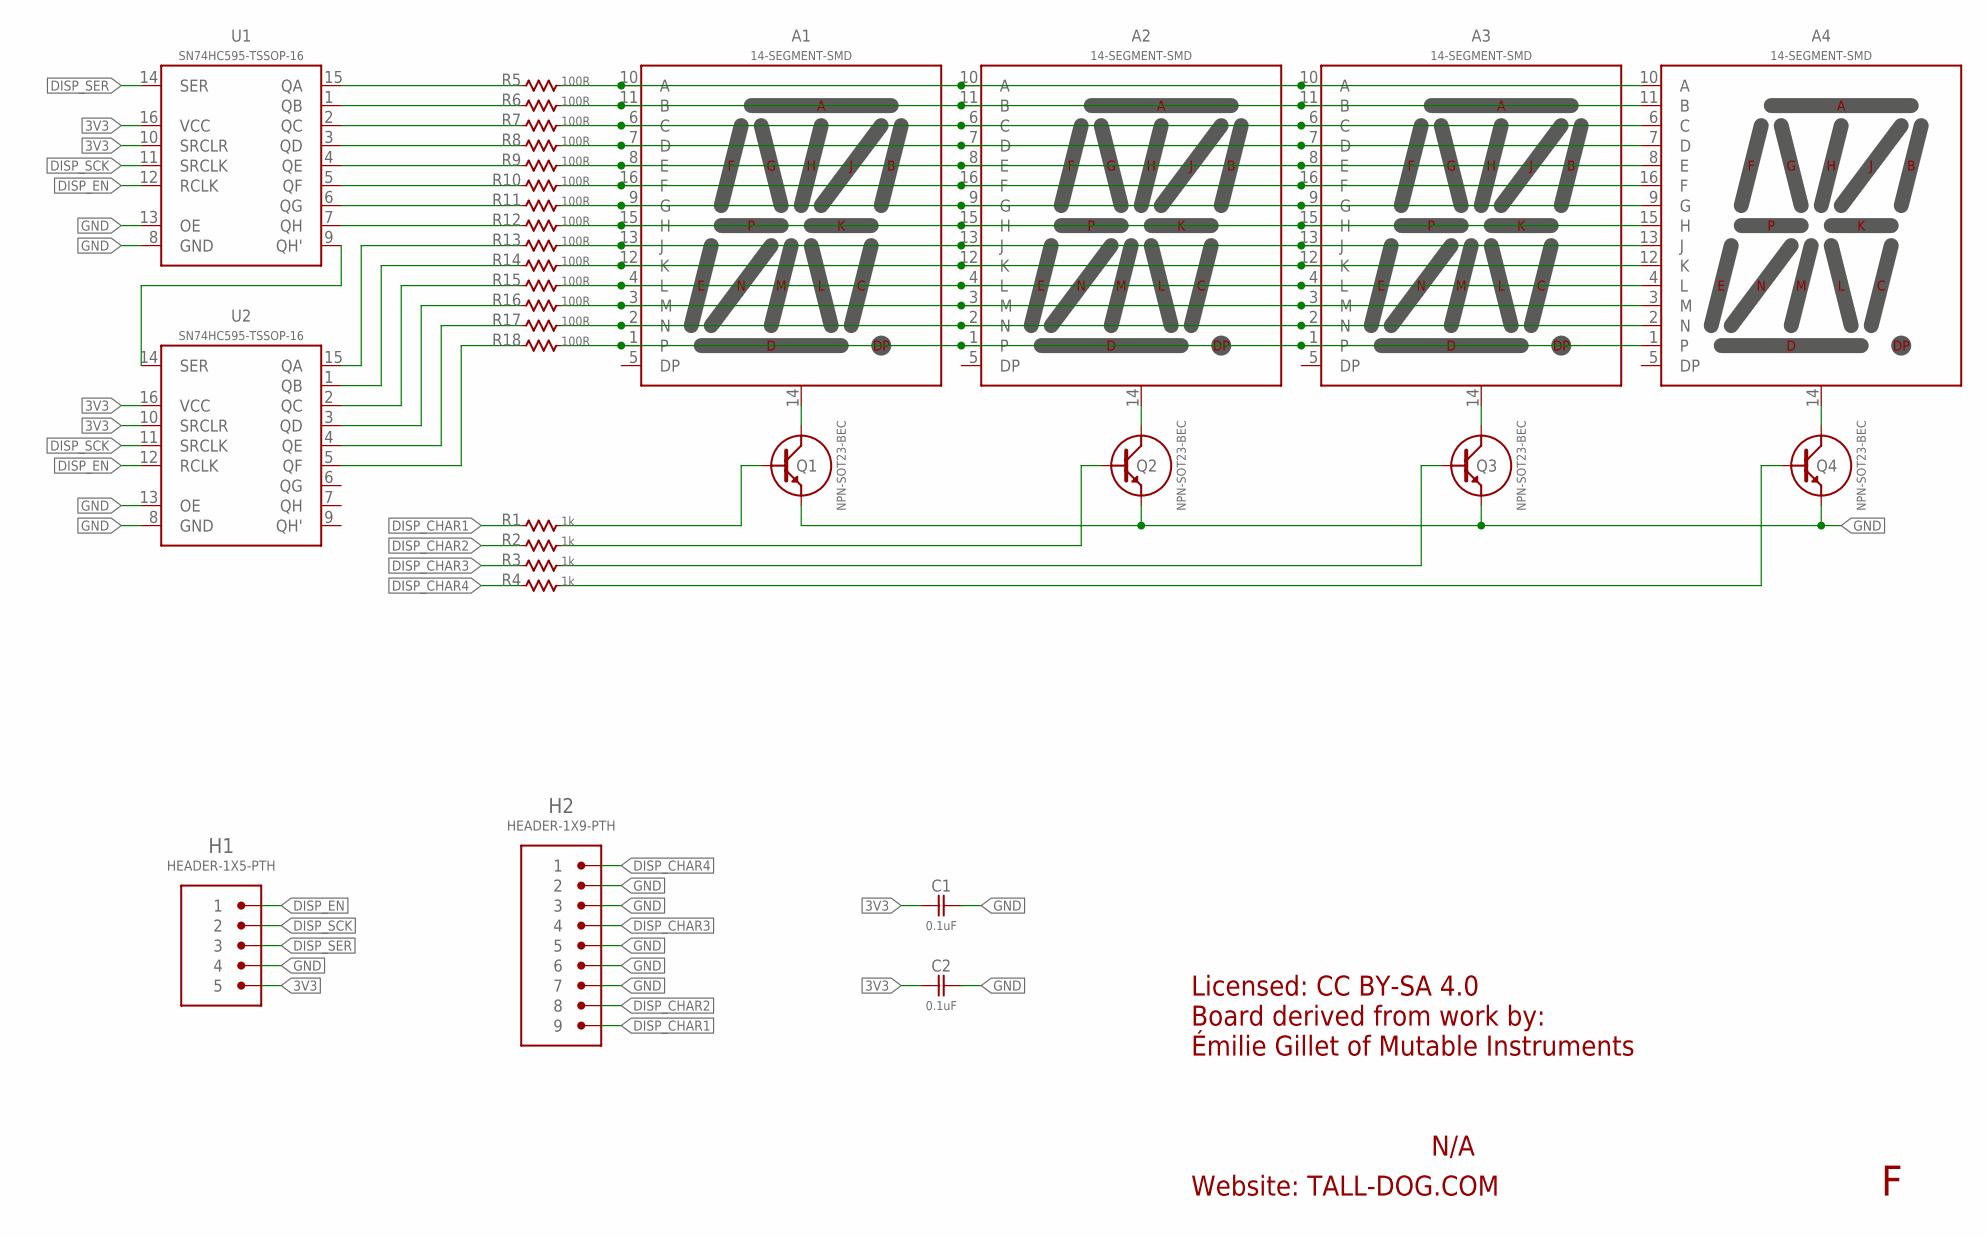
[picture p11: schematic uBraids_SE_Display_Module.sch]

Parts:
A1, A2, A3, A4: 14-SEGMENT-SMD; 14-SEGMENT
C1, C2: 0.1uF; 0603-NP
H1: HEADER-1X5-PTH; PTH-0.1-1X5
H2: HEADER-1X9-PTH; PTH-0.1-1X9
Q1, Q2, Q3, Q4: NPN-SOT23-BEC; SOT-23
R1, R2, R3, R4: 1k; 0603-NP
R5, R6, R7, R8, R9, R10, R11, R12, R13, R14, R15, R16, R17, R18: 100R; 0603-NP
U1, U2: SN74HC595-TSSOP-16; TSSOP-16

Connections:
3V3: C1.1, C2.1, H1.5, U1.10 (SRCLR), U1.16 (VCC), U2.10 (SRCLR), U2.16 (VCC)
A: A1.10 (A), A2.10 (A), A3.10 (A), A4.10 (A), R5.2
A1C: A1.14 (CATHODE), Q1.3 (C)
A2C: A2.14 (CATHODE), Q2.3 (C)
A3C: A3.14 (CATHODE), Q3.3 (C)
A4C: A4.14 (CATHODE), Q4.3 (C)
B: A1.11 (B), A2.11 (B), A3.11 (B), A4.11 (B), R6.2
C: A1.6 (C), A2.6 (C), A3.6 (C), A4.6 (C), R7.2
D: A1.7 (D), A2.7 (D), A3.7 (D), A4.7 (D), R8.2
DISP_CHAR1: H2.9, R1.1
DISP_CHAR2: H2.8, R2.1
DISP_CHAR3: H2.4, R3.1
DISP_CHAR4: H2.1, R4.1
DISP_EN: H1.1, U1.12 (RCLK), U2.12 (RCLK)
DISP_SCK: H1.2, U1.11 (SRCLK), U2.11 (SRCLK)
DISP_SER: H1.3, U1.14 (SER)
E: A1.8 (E), A2.8 (E), A3.8 (E), A4.8 (E), R9.2
F: A1.16 (F), A2.16 (F), A3.16 (F), A4.16 (F), R10.2
G: A1.9 (G), A2.9 (G), A3.9 (G), A4.9 (G), R11.2
GND: C1.2, C2.2, H1.4, H2.2, H2.3, H2.5, H2.6, H2.7, Q1.2 (E), Q2.2 (E), Q3.2 (E), Q4.2 (E), U1.8 (GND), U1.13 (OE), U2.8 (GND), U2.13 (OE)
H: A1.15 (H), A2.15 (H), A3.15 (H), A4.15 (H), R12.2
J: A1.13 (J), A2.13 (J), A3.13 (J), A4.13 (J), R13.2
K: A1.12 (K), A2.12 (K), A3.12 (K), A4.12 (K), R14.2
L: A1.4 (L), A2.4 (L), A3.4 (L), A4.4 (L), R15.2
M: A1.3 (M), A2.3 (M), A3.3 (M), A4.3 (M), R16.2
N: A1.2 (N), A2.2 (N), A3.2 (N), A4.2 (N), R17.2
P: A1.1, A2.1, A3.1, A4.1, R18.2
Q1B: Q1.1 (B), R1.2
Q2B: Q2.1 (B), R2.2
Q3B: Q3.1 (B), R3.2
Q4B: Q4.1 (B), R4.2
RA: R5.1, U1.15 (QA)
RB: R6.1, U1.1 (QB)
RC: R7.1, U1.2 (QC)
RD: R8.1, U1.3 (QD)
RE: R9.1, U1.4 (QE)
RF: R10.1, U1.5 (QF)
RG: R11.1, U1.6 (QG)
RH: R12.1, U1.7 (QH)
RJ: R13.1, U2.15 (QA)
RK: R14.1, U2.1 (QB)
RL: R15.1, U2.2 (QC)
RM: R16.1, U2.3 (QD)
RN: R17.1, U2.4 (QE)
RP: R18.1, U2.5 (QF)
U1-U2: U1.9 (QH'), U2.14 (SER)

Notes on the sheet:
Licensed: CC BY-SA 4.0 Board derived from work by: Émilie Gillet of Mutable Instruments
Website: TALL-DOG.COM
N/A

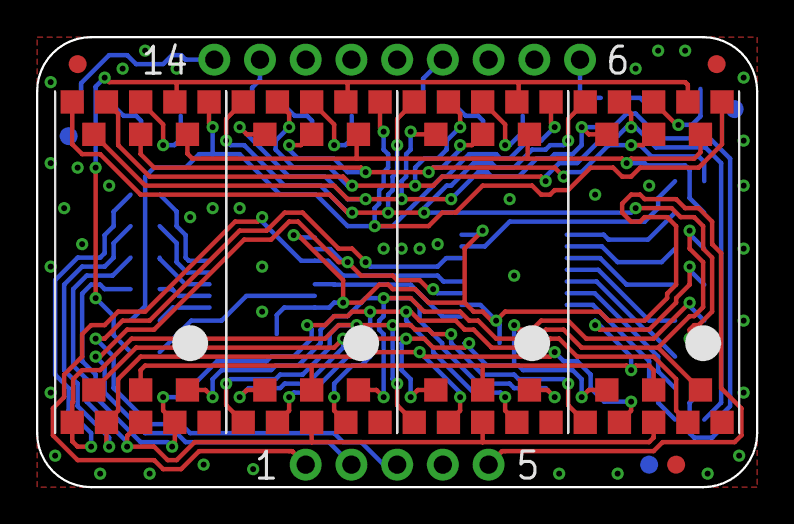
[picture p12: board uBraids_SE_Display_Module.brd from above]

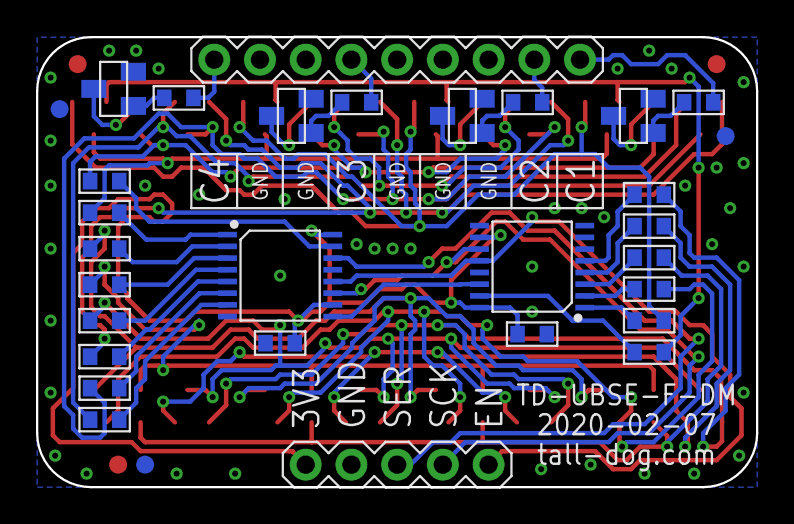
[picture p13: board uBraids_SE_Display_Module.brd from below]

Board: 2 copper layers, 40.0 x 25.0 mm, 38 parts (31 on the bottom side), 46 nets.

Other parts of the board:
U$1, U$2, U$3, U$4, U$5, U$6: FIDUCIAL

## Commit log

2017-10-23 revision C first pass, primarily to address rail clearance
    [uBraids_SE_Display_Module.brd, uBraids_SE_Display_Module.sch, uBraids_SE_Front_Panel.brd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]
2017-10-24 removed additional 0.5 mm from main board, adjusted panel to match
    [uBraids_SE_Front_Panel.brd, uBraids_SE_Main_Board.brd]
2017-10-24 updated BOMs for revision C
    [uBraids_SE_Display_Module.BOM.csv, uBraids_SE_Main_Board.BOM.csv]
2017-10-25 prep for production of revision C
    [uBraids_SE_Display_Module.BOM.csv, uBraids_SE_Display_Module.brd, uBraids_SE_Display_Module.sch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]
2017-12-13 added hardware BOM and the two 3D printed part models
    [uBraids_SE_Encoder_Shim.stl, uBraids_SE_Encoder_Spacer.stl, uBraids_SE_Hardware.BOM.csv]
2017-12-31 very minor changes for new production run
    [uBraids_SE_Display_Module.brd, uBraids_SE_Front_Panel.brd, uBraids_SE_Main_Board.brd]
2018-11-09 removing outdated files
    [uBraids_SE_Encoder_Shim.stl, uBraids_SE_Encoder_Spacer.stl]
2018-11-09 adding new files
    [uBraids_SE_Assembly_Spacer.stl, uBraids_SE_Assembly_Template.brd, uBraids_SE_Model.skp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]
2018-11-09 update for Revision E production
    [uBraids_SE_Display_Module.brd, uBraids_SE_Display_Module.sch, uBraids_SE_Display_Module_BOM.csv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]
2021-03-23 Revision F
    [uBraids_SE_Assembly_Cap.stl, uBraids_SE_Assembly_Spacer.stl, uBraids_SE_Assembly_Template.brd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]
